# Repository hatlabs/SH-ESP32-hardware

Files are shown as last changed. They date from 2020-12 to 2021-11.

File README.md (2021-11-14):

# Sailor Hat for ESP32

This repository contains the Sailor Hat for ESP32 (SH-ESP32) hardware design. SH-ESP32 is a powerful microcontroller development board designed for marine environments.

Special emphasis has been placed on electrical compliance: the board can handle most power surges ever present on an automotive or marine 12V or 24V power system. Equally importantly, the inputs and outputs have protection for electrostatic discharges (static electricity), and are designed to not produce electromagnetic emissions (disturb other sensitive devices such as VHF radios or GPS antennas), and to be protected against electromagnetic interference (will not be disturbed by a VHF, SSB, or a radar).

SH-ESP32 can be used to easily create different types of sensors and control devices for boats. Use scenarios include:

- RPM sensors
- tank level sensors
- bilge sensors
- temperature and humidity sensors
- relay controls (lights, blowers, anchor winch)
- Attitude sensors
- Electronic compasses
- NMEA 2000 gateways
- NMEA 0183 gateways

Some of these applications require a small amount of additional components. Simple add-on boards and designs for these will be made available.

Since the board has native WiFi and NMEA 2000 compatible CAN bus connectivity, it can be used to create boards with either Signal K or native NMEA 2000 connectivity (or both!).

## Features

The main design features include:

- Built around ESP32, a powerful 32-bit microcontroller with 4 MB of flash
- Wide-range 8-32 V power input with surge protection (2-pin pluggable terminal block screw connector)
- NMEA 2000 compatible optoisolated CAN interface (4-pin pluggable terminal block screw connector)
- One optoisolated input and output (4-pin 2.54 mm header)
- 1-Wire interface (3-pin 2.54 mm header)
- I2C interface with both a SparkFun Qwiic connector and a 4-pin 2.54 mm header
- USB interface for programming and serial communication (USB Micro B)
- Provisions for wired Ethernet connectivity with an optional add-on board
- All above interfaces with proper electromagnetic compatibilty (EMC) design -- the device won't interfere with navigational devices or radio equipment
- All interfaces can be disabled or rerouted to different pins
- All general-purpose input/output (GPIO) pins broken out to a separate header
- Through-plated perf board area for custom additions
- Board designed to fit standard low-cost waterproof 100x68x50 mm enclosures

Rendering of a revision 2.0.0 board:

Front side.
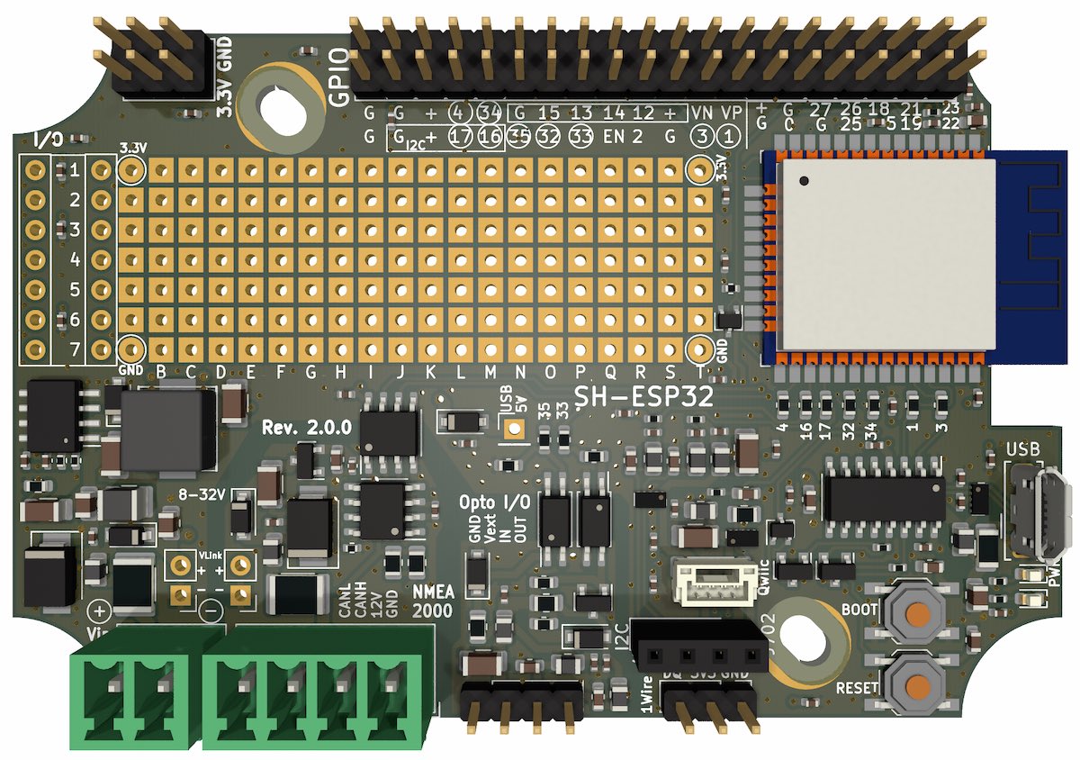
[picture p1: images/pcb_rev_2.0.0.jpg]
Rev. 2.0.0 board


Back side.
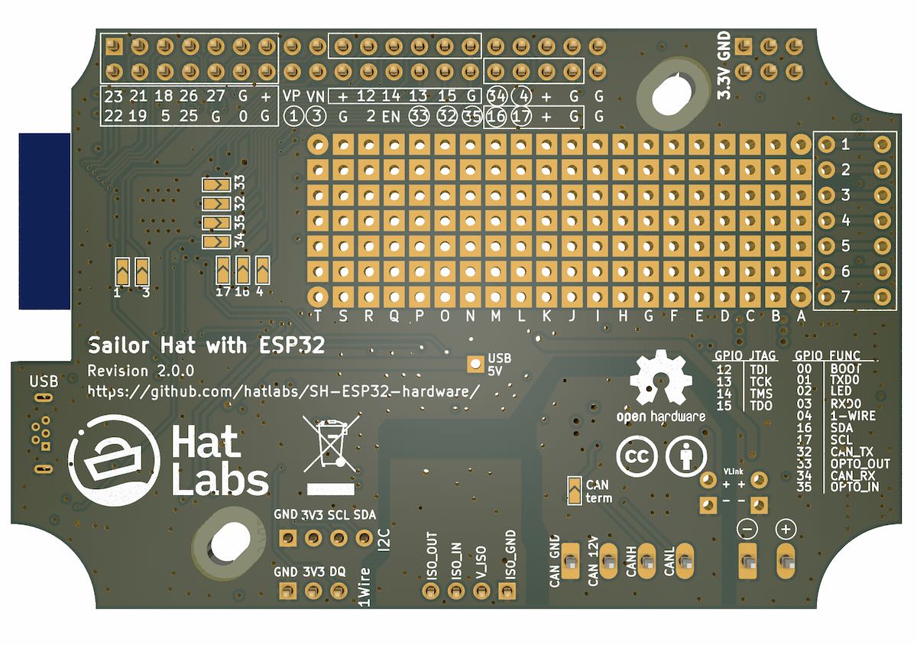
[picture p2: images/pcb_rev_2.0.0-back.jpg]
Rev. 2.0.0 board bottom side


## Getting SH-ESP32

SH-ESP32 is available for purchase at the [Hat Labs web store](https://hatlabs.fi/).

## Documentation

SH-ESP32 documentation is available at the [project GitHub Pages](https://hatlabs.github.io/sh-esp32/).

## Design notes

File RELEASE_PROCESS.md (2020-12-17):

# JLCPCB release process

## Prerequisites

The release process relies on a [jlc-kicad-tools](https://github.com/matthewlai/JLCKicadTools) script.

To install the script, apply the following commands:
    
    pip3 install git+https://github.com/matthewlai/JLCKicadTools
    pip3 install logzero==1.5.0

## Updating metadata

Create a new release branch, e.g. `release_0.2.0`.

Update page title block for both the schema and the layout (File -> Page Settings).

## Creating assembly files

Create assembly files:

### Eeschema

1. Tools -> Generate Bill of Materials
2. Select any BOM and click Generate (we only need the intermediate XML file).

### Pcbnew

1. File -> Plot -> Plot (Output folder "assembly", otherwise default settings are fine)
2. In the same dialog, Generate Drill Files -> Generate Drill File

3. File -> Fabrication Outputs -> Footprint Position File -> Generate Position File (single file)

### Modifying fabrication files for JLCPCB

On the command line:

    ./fix-jlcpcb-files.sh

## Creating the order

Go to jlcpcb.com -> Order now, and upload `assembly.zip` through the "Add your gerber file" button.

The gerber previewer doesn't always work. 
If that's the case, go to the JLCPCB website File Manager and click on Quote on the uploaded file (once the preview has rendered).

Apply the following selections:

- PCB Qty: (as you wish, there's an extra engineering fee above 10, though)
- Impedance: Yes, JLC7628
- PCB Color: green is usually fastest to manufacture
- Surface Finish: ENIG-RoHS (LeadFree HASL-RoHS might be ok)
- Confirm Production file is recommended
- Remove Order Number: Specify a location

Then select SMT Assembly.

- Assemble top side
- Tooling holes: as you like

Accept the terms and Confirm.

Add BOM File: upload `assembly/SH-ESP32_bom_jlc.csv`
Add CPL File: upload `assembly/SH-ESP32_cpl_jlc.csv`

Select Next.

Verify the parts. For SH-ESP32, there should be only 1 part (the JST SH connector) not selected.
Go through the listing and check that the part type and footprint of uploaded BOM data match the matched part detail. 
This is boring but important!
If any of the parts are out of stock, find a replacement on [https://jlcpcb.com/parts](https://jlcpcb.com/parts) and update the schema and the layout and create fabrication files.
If you're absolutely certain that the layout didn't change, you can just re-upload the BOM and CPL files.

Next.

You're in part placement review.
In principle, JLCPCB pre-inspection catches misrotated parts and fixes the rotation, but I've had an IC be 180° misrotated once. 
So, better check.
The viewer doesn't always work.
If that happens, go back and click the next button again until you see the components.
Go through the layout carefully.

If any of the components are misaligned, check the footprint name in `assembly/SH-ESP32_cpl_jlc.csv`.
Then modify the CPL DB (`cpl_rotations_db.csv`).
Add the footprint regex at the top of the file (but under the header line, of course) with the required rotation adjustment. 
Note that if the footprint matches an existing regex, the new regex should be more specific than the old one, and the rotation adjustment should be in relation to the old one. Note that positive degrees are to the counterclockwise.

If you had to modify the CPL DB, rerun the modification script and reupload the BOM and CPL files.

Once the footprint alignments are correct, you want to Download Unselected Parts list for ordering any missing components from LCSC or elsewhere.
Review the unselected parts list to ensure there are no accidental omissions!
You'll hate yourself if you don't!
Note that if you have assigned LCSC part numbers to the unselected parts, you can upload the file to the LCSC BOM tool to create an order for those parts.

Click "Save to Cart". 
You're done with creating the order.

## Updating the Git repo

After ordering the PCBs:

- Commit the changed files.
- Update the release process documentation, if needed!
- Create a new final commit for the assembly directory contents.
- Finally, create a PR against `main`. 
  This PR should _not_ include `assembly` directory, however. 
  We do not want to have the output files in the main branch.
- Merge the PR and you're done!

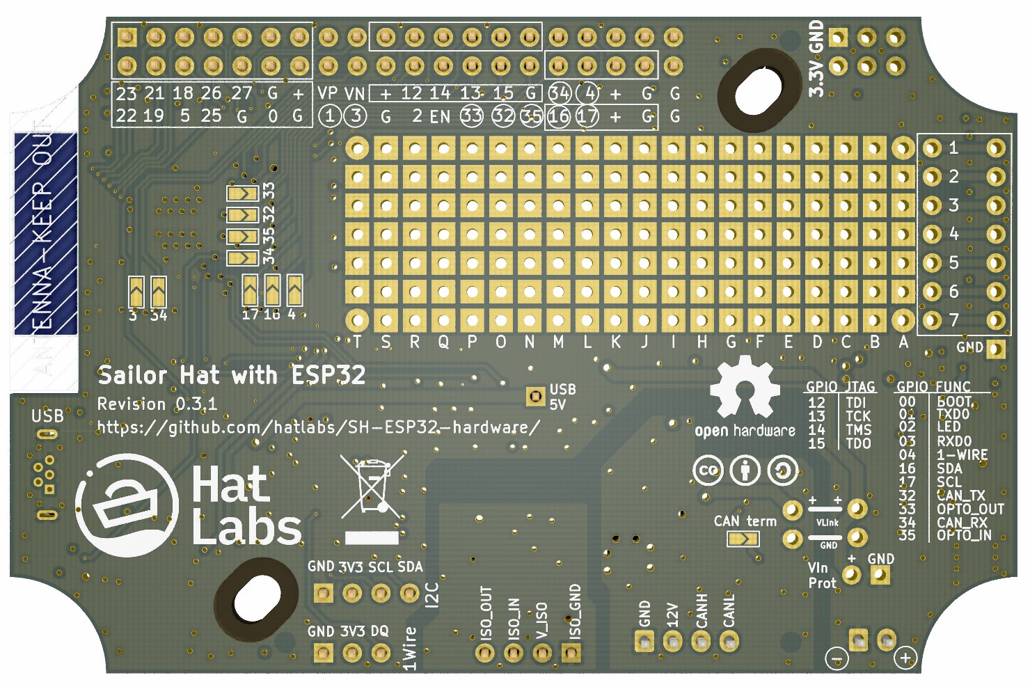
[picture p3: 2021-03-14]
images/pcb_rev_0.3.1-back.jpg

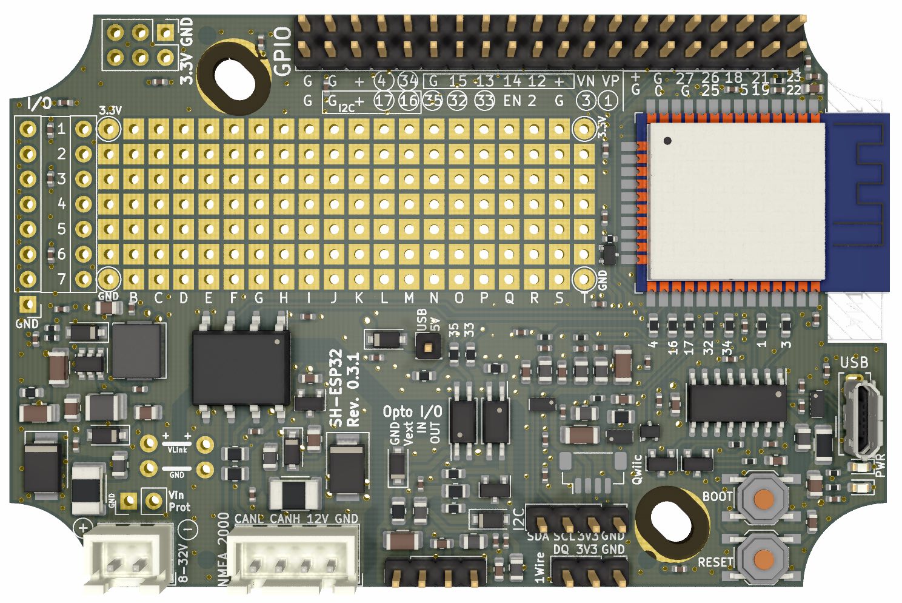
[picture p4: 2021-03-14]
images/pcb_rev_0.3.1.jpg

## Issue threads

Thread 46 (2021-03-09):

Move bypass caps farther from mounting holes

mairas, 2021-03-09:
C1005 and C1025 are uncomfortably close to the mounting holes. I wasn't able to create shorts with the screws but the caps should still be moved further away.

mairas, 2021-08-17:
Done some time ago.

Closed 2021-08-17.

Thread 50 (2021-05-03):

Correct wiring U402

Agilitytime, 2021-05-03:
Hi Together,

is the wiring here correct?
The connectinon do not have to be between D+ and D-?

Best,
Basti

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

mairas, 2021-05-03:
Hi,

Yes, it's correct. 😊 The ESD protection diode array clamps the input voltage of each connected trace to (roughly) -0.6V and 7.8V, dissipating any static electricity discharges before they can damage the inputs of the protected circuitry. Both D+ and D- are individually protected.

See the datasheet here: https://datasheet.lcsc.com/lcsc/1811061308_BORN-RCLAMP0524P-N_C316044.pdf

Closed 2021-08-17.

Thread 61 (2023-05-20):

RFE: hat with multiple digital and analog inputs

mgrouch, 2023-05-20:
Current implementation of esp32 hat is too generic. There is too much DIY required to
build a usable device.

It be nicer if there was esp hat with headers
for multiple digital and analog inputs.

Clearly marked like:

tank1,
tank2,
temp1,
temp2,
rpm1,
rpm2,
press1,
press2,
volt1,
volt2
etc

and generic esp32 firmware with ui (web or LVGL touchscreen) for setting up the sensor readers.

So end user could just use to set up sensors without need to program esp32.

Victron Cerbo GX something similar
for tank level sensors and thermometers.

just an idea
Thanks!

mgrouch, 2023-05-20:
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

Some ideas what inputs can be

mairas, 2023-05-21:
SH-ESP32 is a developer board, not an end user product. I wish you wouldn't make improvement requests in any of the repos I administer; they are not helpful.

Closed 2023-05-21.

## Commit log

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2020-10-17 Update according to comments
    Also add missing connectors and update the fuses
    [ESP32.sch, I2C.sch, SH-ESP32.sch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]
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2020-10-26 Route GPIO traces with min. 0.2mm trace width
    [SH-ESP32.kicad_pcb]
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2020-10-27 Decreased ground fill clearance to fill header gaps
    [SH-ESP32.kicad_pcb]
2020-10-28 Added decoupling caps next to trace vias and copper fill islands
    [ESP32.sch, I2C.sch, PCB.sch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]
2020-10-28 Add logo and licensing information + URL on the bottom silkscreen
    [SH-ESP32.kicad_pcb]
2020-10-30 Change optocoupler types, improve ground planes and a lot of other smaller fixes
    [ESP32.sch, PCB.sch, SH-ESP32.kicad_pcb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]
2020-10-30 Swap optocoupler GPIO pins to connect DAC to output
    Not that it makes a lot of difference: the inverting
    NPN will behave as a hard switch nevertheless
    [ESP32.sch, SH-ESP32.kicad_pcb, power-input.sch]
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2020-11-01 Create a shell script to fix the BOM location and first line
2020-11-01 Add a missing LCSC part number for U901 and U902
    [optocouplers.sch]
2020-11-01 Change I2C pullups to 2k due to missing JLCPCB basic parts(!)
    [I2C.sch]
2020-11-02 Apply pullup change to the PCB design as well
    [SH-ESP32.kicad_pcb]
2020-11-07 Fix the library for HT75xx
    [canbus.sch]
2020-11-13 Add vertical USB and JTAG Connectors tp PCB
    [ESP32.sch, SH-ESP32.kicad_pcb]
2020-11-14 Revamp Prototype Area for external I/O connector and accomodate 'Hat' / Daughter board.
    [ESP32.sch, SH-ESP32.kicad_pcb, power-input.sch]
2020-11-15 Added missing JTAG label, Labled JTAG Pins, changed Header for user I/O Connector to make Pin 1 'round'
    [SH-ESP32.kicad_pcb]
2020-11-16 Add missing 3d shapes and GND label for J302
    [SH-ESP32.kicad_pcb]
2020-11-16 WireLink from VCAN to VIN + protection diode.
    [ESP32.sch, SH-ESP32.kicad_pcb, canbus.sch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]
2020-11-17 Support for OLED/LCD mini displays to direct plug to I2C header - Moved Pin header and Qwiic connectors and re-arranged I2C area. - Fixed silk screen accordingly - Also shoved USB conx 0.3mm and alig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
    [I2C.sch, SH-ESP32.kicad_pcb]
2020-11-17 Play with the USB differential pair to make it more straight
    [SH-ESP32.kicad_pcb, USB.sch]
2020-11-18 Use schottkys instead of MOSFETs for polarity protection
    Also add a fuse to USB 5V and change the CAN terminator jumper
    into a solder jumper.
    [ESP32.sch, I2C.sch, PCB.sch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]
2020-11-18 Add a filter cap in front of the USB 5V bead
    [I2C.sch, SH-ESP32.kicad_pcb, USB.sch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]
2020-11-18 Add a missing 3D shape for the USB fuse
    [SH-ESP32.kicad_pcb]
2020-11-18 Final track tidyup and image generation - Ensured all power tracks are consistent 1mm (fixed a couple) - Re-routed DQ and BOOT signals to better avoid screw, and route totaly on top of board, removin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
    [SH-ESP32.kicad_pcb, USB.sch]
2020-11-19 Move the rescued USB connector to the SH-ESP32 library
    [USB.sch]
2020-11-19 Rotate silkscreen vertical texts to be oriented down-to-up
    [SH-ESP32.kicad_pcb]
2020-11-19 Tweak the buck converter traces to better conform to datasheet recommendations
    [SH-ESP32.kicad_pcb]
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2020-11-20 - Swapped TXD0 & RXD0 between ESP32 and CH340C (U401) - (at the 0 Ohm Links) - U401 -> Pin 16 (VCC switched to 3V3) - U401 -> Pin 4 (V3) taken to 3V3
    [ESP32.sch, USB.sch]
2020-11-20 Removed C401 as not needed in 3V3 power mode on CH230C
    [USB.sch]
2020-11-20 Brought in all corner arcs by 1.5mm and re-arranged / re-routed accordingly. - Modeled Box outlines on Drawing layer. - Move mounting hole near buttons to correct spot - Major changes to bottom right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
    [SH-ESP32.kicad_pcb]
2020-11-20 Schematic of changes and more Measurments on the Box / PCB Drawing
    [ESP32.sch, SH-ESP32.kicad_pcb, UI.sch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]
2020-11-23 Changed R905 to 0805 FP and value to 2.2k
    [SH-ESP32.kicad_pcb, optocouplers.sch]
2020-11-24 Initial version with 40Pin header for Ethernet and re-route.
    [ESP32.sch, SH-ESP32.kicad_pcb, SH-ESP32.sch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]
2020-11-24 Add missed ESP32 Schematic to commit
    [ESP32.sch]
2020-11-24 Pinout revamp after review and tidy up. - LED and DQ returned to current pins on Rev 0.1 - Freed JTAG pin from duplicate IO duty.
    [ESP32.sch, SH-ESP32.kicad_pcb]
2020-11-24 Updated Silkscreen for new GPIO pinout - Moved power header onto 0.1" grid with IO header. - Scattered GND vias.
    [ESP32.sch, SH-ESP32.kicad_pcb]
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2020-11-24 Moved Sensor VP to allow Edge plane and added many GND Via's to support top / bottom planes
    [SH-ESP32.kicad_pcb]
2020-11-24 Added a bunch of vias and tweaked the silkscreens
    Also shoved some decoupling caps and vias a bit around to increase
    ground fill areas.
    [ESP32.sch, SH-ESP32.kicad_pcb]
2020-11-24 Add 3d shapes for BAT54As
    Again, the shapes aren't quite correct but close enough.
    [SH-ESP32.kicad_pcb]
2020-11-25 Tweak some vias under the ESP32 to improve power plane fill
    [SH-ESP32.kicad_pcb]
2020-11-25 Nudged GPIO header labels to not overlap decoupling caps
    [SH-ESP32.kicad_pcb]
2020-11-25 Swap power plug pins and reorganize components and silk screen around the area
    [SH-ESP32.kicad_pcb, power-input.sch]
2020-11-25 Add an unpopulated pad for extra opto output pullup
    [PCB.sch, SH-ESP32.kicad_pcb, optocouplers.sch]
2020-11-25 ReRoute EN track to be cleaner / away from Antenna
    [SH-ESP32.kicad_pcb]
2020-11-25 Make the USB 5V conx a single-pin test pad for safety
    [ESP32.sch, SH-ESP32.kicad_pcb]
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2020-11-26 Convert USB to Vertical Thru-Hole - Fix Git-ignore for ALL cache files
    [SH-ESP32.kicad_pcb, USB.sch]
2020-11-26 - Fixed LCSC part number of USB Connector - Change CPU to ESP32-WROOM32E part (was D) and fixed LCSC part number - Fixed Name / silkscreen for Blank Tempalte
    [ESP32.sch, SH-ESP32-Blank.kicad_pcb, SH-ESP32-Blank.sch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]
2020-11-26 Change buck converter inductor to something available at JLCPCB
    [SH-ESP32.kicad_pcb, power-input.sch]
2020-11-26 Adjust track width of Hi_Freq traces for Ethernet. Reduce CLK to 2mm trace
    [SH-ESP32.kicad_pcb]
2020-11-27 Swap D602 to B5819W which is a standard component
    Due to the larger footprint, some layout changes were required.
    [SH-ESP32.kicad_pcb, canbus.sch]
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2020-11-30 Fix C603 part number to match the footprint
    [SH-ESP32.kicad_pcb, canbus.sch]
2020-12-03 Switch power and NEMA to JST-XH Connectors and update silkscreen accordingly
    [SH-ESP32.kicad_pcb, canbus.sch, power-input.sch]
2020-12-03 - Removed Extra 'NEMA' pinout from mid board silkscreen - Cutout board under ESP32 Antenna as per HW Design Spec for WROOM module.
    [SH-ESP32.kicad_pcb]
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2020-12-03 Updated Hat Blank for form factor changes to SH-ESP32 (XH Connectors)
    [SH-ESP32-Blank.kicad_pcb]
2020-12-17 Increase thermal clearances of copper fills to improve solderability
    Also swapped the 120R 1206 termination resistor to two 240R 0805
    resistors due to JLCPCB basic catalog availability.
    [SH-ESP32.kicad_pcb, canbus.sch]
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2020-12-17 Change an NPN LCSC part no. according to availability
    [SH-ESP32.kicad_pcb, optocouplers.sch]
2020-12-17 Tweak the copper fill zones a bit more
    All zones have now the same settings:
    - 0.3mm clearance (JLCPCB min. 0.127mm)
    - 0.2mm minimum width
    - 0.3mm thermal clearance
    - All pads with thermal reliefs
    - 0.5mm thermal spoke width
    [SH-ESP32.kicad_pcb]
2020-12-18 Change mounting holes to slots to suit multiple box vendors with variable mounting positions. - Move GPIO Connect along and re-routed. (removed 'edge' trace) - Move VIN_Prot to near main power connec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
    [PCB.sch, SH-ESP32.kicad_pcb]
2020-12-19 Modify ESP32 footprint for Hand Soldering - Extended all pads 1mm outwards - Rearranged 0-Ohm links and EN/CLK area for new footprint - Added 3V3 and GND pads to corners of Prototype Area - Tidied up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
    [ESP32.sch, SH-ESP32.kicad_pcb]
2020-12-19 Fixed spacing on TXD/RXD 0-Ohm Links
    [SH-ESP32.kicad_pcb]
2020-12-19 Update HAT-Proto to V0.3 Pin header locs and fix outline for box corners
    [IOHeader.sch, PCB.sch, SH-ESP32-HAT-Proto.kicad_pcb]
2020-12-19 Change 'unconnected' holes to Square pads - Fixed DRC errors
    [IOHeader.sch, SH-ESP32-HAT-Proto.kicad_pcb]
2020-12-19 Updated Prot-Blank to R 0.3 matching header pos etc
    [IOHeader.sch, PCB.sch, SH-ESP32-Blank.kicad_pcb]
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2020-12-22 Move N2K Connector to avoid pins hitting case PCB Standoff (underneath). - Increase mask on hole for screw flanges - Move some vias away from mounting holes for better clearence for large screw flang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
    [SH-ESP32.kicad_pcb]
2021-01-04 Power system bug fix. Changed fuses & Diode - Swapping incorrect part D1101 and D1102 to BAT54A / LCSC: C83936 -Removed Perfect Diode, replaced with B5819W Schottky - Replaced USB PTC Fuse ( F401 ) w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
    [ESP32.sch, I2C.sch, PCB.sch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]
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2021-01-18 Fix Revision on back silkscreen
    [SH-ESP32.kicad_pcb]
2021-01-28 Add an LC pi filter to buck converter input
    The filter is required to limit conducted noise emissions.
    Additionally, buck inductor is changed and the whole SMPS region
    is rearranged. Update title block data.
    [ESP32.sch, I2C.sch, PCB.sch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]
2021-01-29 Fix regulator layout according to comments
    Added a copper fill for the IN trace. Removed thermal reliefs from
    a few pads. Added a lot of ground stitching vias.
    [SH-ESP32.kicad_pcb]
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2021-01-29 Update the SMTA fixing script to allow PCB-only orders
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2021-01-30 Fix D1101 and D1102 part numbers
    [ESP32.sch]
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2021-01-31 Properly detect BOM source files in JLC fix script
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2021-02-15 Swap Power and CAN connector pins to have GND on pin 1
    This complies e.g. with all pre-made pigtails.
    [SH-ESP32.kicad_pcb, canbus.sch, power-input.sch]
2021-02-15 Fix back silkscreen, remove a redundant via
    [SH-ESP32.kicad_pcb]
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2021-02-17 Replace the 3.3V plane under the PSU section with a ground fill
    [SH-ESP32.kicad_pcb]
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2021-02-17 Fix a bypass cap location (DRC error)
    [SH-ESP32.kicad_pcb]
2021-02-18 Swap 1-Wire and QWICC Connectors so 1-wire is on the edge, and can access when LCD on.
    [SH-ESP32.kicad_pcb]
2021-02-18 Reduce 1-wire RC filter capacitor value
    RC filter design guidelines were from a 5V system and from a driver
    that could probably drive the line harder than the ESP32. Reduce
    the filter cap to 1uF for a better performance.
    [onewire.sch]
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2021-02-21 Remove the keep-out zone from ESP32-WROOM-32 footprint
    It would cause problems with panelization.
    [SH-ESP32.kicad_pcb]
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2021-03-04 Fix 2-pin header part number
    [power-input.sch]
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2021-04-26 Swap BAT54As to SOT-323 to improve availability
    [ESP32.sch, SH-ESP32.kicad_pcb]
2021-04-26 Replace L302 for better availability
    [SH-ESP32.kicad_pcb, power-input.sch]
2021-04-26 J302 should be virtual to prevent hand-soldering
    [SH-ESP32.kicad_pcb]
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2021-08-13 Replace buck converter and CAN transceiver ICs
    IC substitutions necessitated by component supply issues.
    Other changes:
    - Buck converter layout changes due to larger peripherals
    - Isolated CAN transceiver replaced by separate digital isolators
    and transceivers. Layout changes.
    - Changed JST XH conx to easier-to-use Phoenix MCs
    - Removed dedicated Vin Prot conx (still available via VLink)
    - Removed dedicated GND from left I/O header
    [ESP32.sch, I2C.sch, PCB.sch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]
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2021-11-14 Fix buck FF capacitor value and part number
    [SH-ESP32.kicad_pcb, power-input.sch]
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2021-12-31 Fix PCB DRC errors
    Seems like KiCad 6 is a bit more strict wrt. DRC than Kicad 5.
    [SH-ESP32.kicad_pcb]
2021-12-31 Rename Ferrite_Bead to FerriteBead
    Symbol name changed between KiCad 5 and 6...
    [ESP32.kicad_sch, I2C.kicad_sch, USB.kicad_sch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]
2021-12-31 Fix DRC errors reported by KiKit CLI
    [SH-ESP32.kicad_pcb]
2021-12-31 One more component swap due to part availability
    [ESP32.kicad_sch, SH-ESP32.kicad_sch, power-input.kicad_sch]
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2022-07-07 Only use the edge signal pins of RCLAMPs if possible
    This improves resiliency to slight misalignment during manufacturing.
    [I2C.kicad_sch, SH-ESP32.kicad_pcb, onewire.kicad_sch]
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2023-08-10 Fix component rotations
    [ESP32.kicad_sch, I2C.kicad_sch, SH-ESP32.kicad_pcb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]
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2024-06-29 Go back to ISO1050 for CAN transceiver
    Also add CAN RX and TX LEDs and beef up buck capacitors
    as much as space allows.
    [ESP32.kicad_sch, I2C.kicad_sch, PCB.kicad_sch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]
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2024-10-16 Fix copper fills
    [SH-ESP32.kicad_pcb]
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
